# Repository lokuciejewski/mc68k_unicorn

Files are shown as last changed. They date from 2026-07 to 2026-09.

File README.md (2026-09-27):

# Unicorn - a mc68k-based SBC

This SBC was created with one goal in mind - to run UNIX or UNIX-like OS on it. In order to achieve this, the Motorola 68010 had to be chosen since it's the first mc68k family member to support virtual memory (at least in the basic form) and is able to cooperate with a MMU natively.

## Hardware V1

### V1 description

The board is designed in KiCad. The main specs are:

- Motorola 68010 CPU @ 8.192Mhz
- 1MB of SRAM in the form of 2x AS6C4008 (512k x 8) modules
- 64kB of ROM in the form of 2x AT28C256 (32k x 8) modules
- Xilinx xc9572xl CPLD used as glue logic and simple PMMU
- Motorola MC68681 DUART chip for IO
- PCF8584P I2C controller

The board uses two voltage rails, 5V and 3V3, with the latter being used to power the CPLD only and the rest of the system being powered from the 5V. The 3V3 regulator derives its voltage from the 5V rail which is supplied via the USB-C plug which also doubles as the UART1 (`Serial A`) input/output. The board has a DB9 socket which is connected via MAX232 to the 68681 DUART on UART2 (`Serial B`). Additionally, there is a JTAG header for programming the CPLD and two headers for I2C and SPI. 3 programmable LEDs and 3 inputs are available to the user.

#### Memory map

The memory map is defined by the CPLD and is kept as simple as possible:

|Address range|Size [bytes]|Contents|
|---|---|---|
|0x000000 - 0x00FFFF|64k|ROM|
|0x010000 - 0x1FFFFF|1M|SRAM|
|0x110000 - 0x1100FF|256|68681 DUART|
|0x110100 - 0x1101FF|256|8584P I2C|

### V1 conclusions

The board needed a few small adjustments but otherwise functions correctly. Its main problems are very slow SPI bus (bit-banged) and not enough pins on the CPLD to connect all necessary signals for it to function as the PMMU.

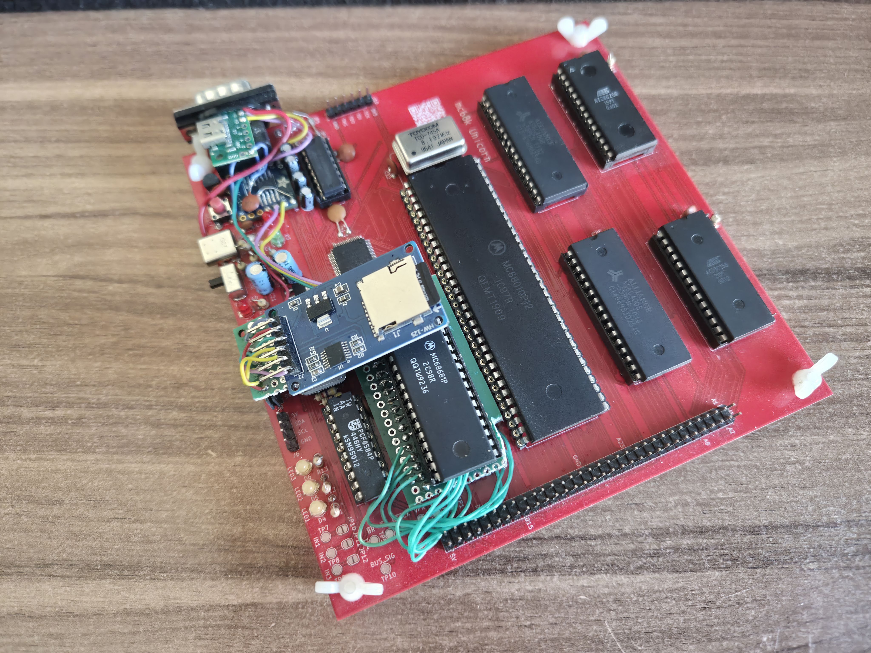
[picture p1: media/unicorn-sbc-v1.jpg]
Unicorn SBC V1 with all its bodge wires :)


## Hardware V2

Changes scheduled for the hardware revision 2:

- Add clock divider circuit to allow for different clocks to be derived and used throughout the system
- Add hardware solution to the SPI - either inside the CPLD or as a separate circuit
- [Optional] Remove the I2C circuit since bit-banged I2C should be sufficient
- Add an RTC on the I2C bus
- Add the SD card slot directly to the board
- Move to the 100 pin version of the CPLD to accomodate all signals
- General layout fixes - USB, DUART data lines etc.

### Further changes

A DRAM controller and a SIMM socket(s) would allow this SBC to address even more memory, up to 68010's 16MB natively and even more through paging. This would require adding a second CPLD or even swapping the current CPLD with a FPGA. While this is not required to reach the goal of running UNIX, it would significantly expand the SBC's capabilities.

## Software

### Firmware description

The board can run any software compiled with the `m68k-elf-gcc` or equivalent m68k compiler. It can utilize its own fork of [`picolibc`](https://github.com/lokuciejewski/picolibc-unicorn) which implements some of the stdlib's functions. The supplied [bootloader](./software/firmware/) allows loading any `.elf` file from the SD card and running it. The bootloader comes with a small monitor - a customized [`tinylisp`](https://github.com/Robert-van-Engelen/tinylisp) implementation.

The bootloader mounts the SD card (FAT16-formatted) and searches for the file named `bootord`. It then tries to load a file that's in the `bootord` into the memory at address `0x10000`. After that, it tries to execute the executable.

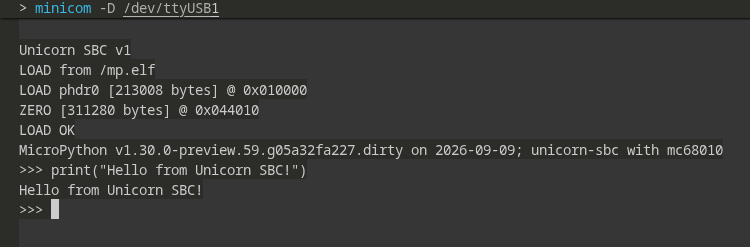
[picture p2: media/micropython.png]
Booting the micropython elf


### Architecture-specific design decisions

Motorola 68010, unlike the 68000 allows for relocating the interrupt vector table into an arbitrary address in its memory space. The Unicorn SBC's bootloader allocates the interrupt vector table at the top of its base 1M of SRAM, at address `0x10FC00`. This 1KB is reserved by the system and must never be accessed by the application directly.

### Compiling the software

#### Requirements

- [`m68k-elf-gcc`](https://github.com/kentosama/m68k-elf-gcc) compiler or any other C compiler that supports the m68k architecture. With a bit of fiddling, the newer GCC can be built, I used `gcc-16.2.0` with the following configuration options: `--prefix=/tmp/m68k-elf-gcc/m68k-toolchain --build=x86_64-pc-linux-gnu --host=x86_64-pc-linux-gnu --target=m68k-elf --program-prefix=m68k-elf- --enable-languages=c --enable-obsolete --enable-lto --disable-threads --disable-libmudflap --disable-libgomp --disable-nls --disable-werror --disable-libssp --disable-shared --disable-multilib --disable-libgcj --disable-libstdcxx --disable-gcov --without-headers --without-included-gettext --with-cpu=m68010 --with-newlib`
- [A fork of `picolibc`](https://github.com/lokuciejewski/picolibc-unicorn) which needs to be installed into the above toolchain
- An SD card formatted in FAT16

The [`example-app`](./software/apps/example_app/) can be used as a base for any software that is to be compiled and ran on the Unicorn SBC. The most important are the [`linker script`](./software/apps/example_app/unicorn_app_v1.ld), the [`crt0.c`](./software/apps/example_app/crt0.c) and the [`CMakeLists.txt`](./software/apps/example_app/CMakeLists.txt).

#### Caveats

The `picolibc` automatically allocates all unused memory reserved for the application in the linker script as a heap space, so during the compilation it will always show 100% memory is consumed. As far as I know, there is no way of limiting the size except for setting the minimum heap size.

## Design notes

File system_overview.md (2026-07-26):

# mc68k SBC - Unicorn v1

## System Overview

- CPU: mc68c010 @ 4Mhz
- RAM: 2x 512k AS6C4008-55PCN SRAM
- ROM: 2x AT28c256 EEPROM
- MMU & glue logic: xc9572xl CPLD
- Peripherals:
  - 68681 DPUART chip - one UART connected via FT231 to USB-C and another connected via MAX232 to DB-9
  - SPI-capable (software) bus from 68681
  - I2C bus using PCF8584
- Power: 5V rail from the USB-C and 3v3 rail derived using ams1117-3.3

## Memory map

A first simple memory map to test the board and get the system running.

0x000000 - 0x00ffff: ROM
0x010000 - 0x03ffff: SRAM (user space)
0x040000 - 0x10ffff: SRAM (kernel space)
0x110000 - 0x110fff: 68681 DPUART (UART1, UART2 and SPI)
0x111000 - 0x111fff: PCF8584 (I2C)

## Glue logic

xc9572xl is connected to all necessary lines to perform the role of a glue logic:

- Address lines:
  - A1 --> PIN1
  - A2 --> PIN2
  - A3 --> PIN4
  - A4 --> PIN5
  - A5 --> PIN6
  - A6 --> PIN7
  - A7 --> PIN8
  - A8 --> PIN9
  - A9 --> PIN10
  - A10 --> PIN11
  - A11 --> PIN12
  - A12 --> PIN13
  - A13 --> PIN15
  - A14 --> PIN16
  - A15 --> PIN17
  - A16 --> PIN18
  - A17 --> PIN19
  - A18 --> PIN20
  - A19 --> PIN22
  - A20 --> PIN23
  - A21 --> PIN24
  - A22 --> PIN25
  - A23 --> PIN27
- CPU signals:
  - /AS --> PIN31
  - /UDS --> PIN32
  - /LDS --> PIN33
  - /DTACK --> PIN34
  - /RW --> PIN35
  - CLK --> PIN36
  - /IPL0 --> PIN38
  - /IPL1 --> PIN39
  - /IPL2 --> PIN40
  - /RES --> PIN42
  - /HALT --> PIN43
  - FC2 --> PIN44
  - FC1 --> PIN45
  - FC0 --> PIN46
- Glue logic signals:
  - /ROM_CS --> PIN47
  - /ROM_LB_OE --> PIN48 (ROM Lower Byte OE)
  - /ROM_UB_OE --> PIN49 (ROM Upper Byte OE)
  - /RAM_CS --> PIN50
  - /RAM_LB_OE --> PIN51 (RAM Lower Byte OE)
  - /RAM_UB_OE --> PIN52 (RAM Upper Byte OE)
  - /RAM_LB_WE --> PIN56
  - /RAM_UB_WE --> PIN57
  - /I2C_CS --> PIN58
  - /I2C_IACK --> PIN59
  - /I2C_IRQ --> PIN60
  - /68681_CS --> PIN61
  - /68681_IACK --> PIN62
  - /68681_IRQ --> PIN63
  - PLD_SIG --> PIN64 (signal to/from the expander)

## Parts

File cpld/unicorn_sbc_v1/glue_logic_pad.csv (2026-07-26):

Release 8.1i - Fit P.20131013
Copyright(c) 1995-2003 Xilinx Inc. All rights reserved
7-26-2026 7:06PM
NOTE: This file is designed to be imported into a spreadsheet program
such as Microsoft Excel for viewing | printing and sorting. The comma ' | '
character is used as the data field separator.
This file is also designed to support parsing.
Input file: glue_logic.ngd
output file: glue_logic_pad.csv
Part type: xc9572xl
Speed grade: -10
Package: vq64
Pinout by Pin Number:
----- | ----- | ----- | ----- | ----- | ----- | ----- | ----- | ----- | -----
Pin Number | Signal Name | Pin Usage | Pin Name | Direction | IO Standard | IO Bank Number | {blank} | Slew Rate | Termination | {blank} | Voltage | Constraint
P1 | I2C_IRQ_n | I | I/O | INPUT
P2 | RES_n | GTS | I/O/GTS2
P3 | VCC |  | VCCINT
P4 | ROM_LB_OE_n | O | I/O | OUTPUT
P5 | A15 | I | I/O/GTS1 | INPUT
P6 | ROM_UB_OE_n | O | I/O | OUTPUT
P7 | TIE |  | I/O
P8 | UDS_n | I | I/O | INPUT
P9 | IPL0_n | O | I/O | OUTPUT
P10 | A16 | I | I/O | INPUT
P11 | TIE |  | I/O
P12 | A19 | I | I/O | INPUT
P13 | A21 | I | I/O | INPUT
P14 | GND |  | GND
P15 | AS_n | GCK/I | I/O/GCK1
P16 | CLK | GCK | I/O/GCK2
P17 | TIE |  | I/O/GCK3
P18 | ROM_CS_n | O | I/O | OUTPUT
P19 | RAM_CS_n | O | I/O | OUTPUT
P20 | TIE |  | I/O
P21 | GND |  | GND
P22 | IPL2_n | O | I/O | OUTPUT
P23 | TIE |  | I/O
P24 | I2C_IACK_n | O | I/O | OUTPUT
P25 | TIE |  | I/O
P26 | VCC |  | VCCIO
P27 | BERR_n | O | I/O | OUTPUT
P28 | TDI |  | TDI
P29 | TMS |  | TMS
P30 | TCK |  | TCK
P31 | TIE |  | I/O
P32 | TIE |  | I/O
P33 | TIE |  | I/O
P34 | DPUART_IACK_n | O | I/O | OUTPUT
P35 | HALT_n | O | I/O | OUTPUT
P36 | A9 | I | I/O | INPUT
P37 | VCC |  | VCCINT
P38 | A22 | I | I/O | INPUT
P39 | A20 | I | I/O | INPUT
P40 | IPL1_n | O | I/O | OUTPUT
P41 | GND |  | GND
P42 | A17 | I | I/O | INPUT
P43 | DTACK_n | O | I/O | OUTPUT
P44 | DPUART_CS_n | O | I/O | OUTPUT
P45 | A12 | I | I/O | INPUT
P46 | A11 | I | I/O | INPUT
P47 | A23 | I | I/O | INPUT
P48 | RW_n | I | I/O | INPUT
P49 | A18 | I | I/O | INPUT
P50 | RAM_LB_OE_n | O | I/O | OUTPUT
P51 | I2C_CS_n | O | I/O | OUTPUT
P52 | A14 | I | I/O | INPUT
P53 | TDO |  | TDO
P54 | GND |  | GND
P55 | VCC |  | VCCIO
P56 | A13 | I | I/O | INPUT
P57 | A10 | I | I/O | INPUT
P58 | DPUART_IRQ_n | I | I/O | INPUT
P59 | LDS_n | I | I/O | INPUT
P60 | RAM_LB_WE_n | O | I/O | OUTPUT
P61 | RAM_UB_OE_n | O | I/O | OUTPUT
P62 | A8 | I | I/O | INPUT
P63 | RAM_UB_WE_n | O | I/O | OUTPUT
P64 | TIE |  | I/O/GSR
To preserve the pinout above for future design iterations in
Project Navigator simply execute the (Lock Pins) process
located under the (Implement Design) process in a toolbox named
(Optional Implementation Tools) or invoke PIN2UCF from the
command line. The location constraints will be written into your
specified UCF file

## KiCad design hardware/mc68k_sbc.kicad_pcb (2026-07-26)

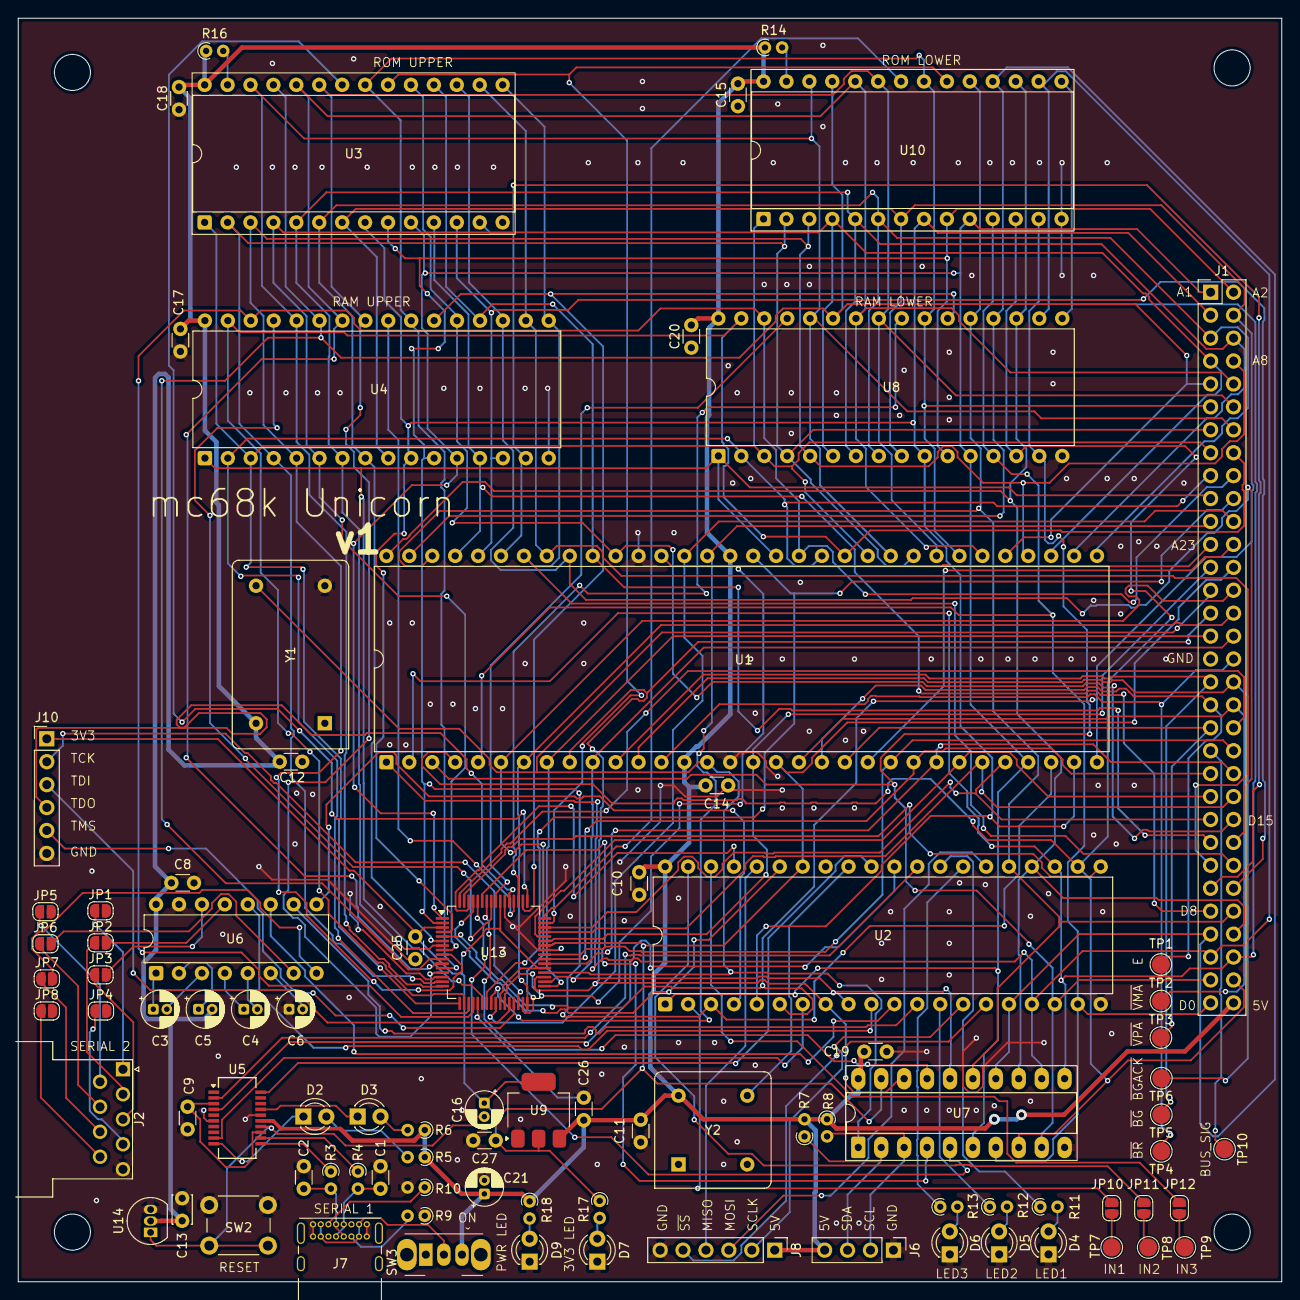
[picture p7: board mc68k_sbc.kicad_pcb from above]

Board: 2 copper layers, 140.0 x 140.0 mm, 88 parts (0 on the bottom side), 144 nets.

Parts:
C1, C2: 47pF; C_Disc_D3.0mm_W1.6mm_P2.50mm
C3, C4, C5, C6: 1uF; CP_Radial_D4.0mm_P1.50mm
C8, C9, C10, C11, C12, C14, C15, C17, C18, C19, C20, C25, C26, C27: 0.1uF; C_Disc_D3.0mm_W1.6mm_P2.50mm
C13: 1uF; C_Disc_D3.0mm_W2.0mm_P2.50mm
C16, C21: 10uF; CP_Radial_D4.0mm_P1.50mm
D2, D3, D4, D5, D6, D7, D9: LED; LED_D3.0mm
J1: EXP; PinHeader_2x32_P2.54mm_Vertical
J2: DE9_Pins; DSUB-9_Pins_Horizontal_P2.77x2.54mm_EdgePinOffset9.40mm
J6: I2C_Conn; PinHeader_1x04_P2.54mm_Vertical
J7: USB_C_Receptacle_USB2.0_14P; USB_C_Receptacle_GCT_USB4085
J8: SPI_Conn; PinHeader_1x06_P2.54mm_Vertical
J10: JTAG_Conn; PinHeader_1x06_P2.54mm_Vertical
JP1: DCD; SolderJumper-2_P1.3mm_Open_RoundedPad1.0x1.5mm
JP2: RXD; SolderJumper-2_P1.3mm_Open_RoundedPad1.0x1.5mm
JP3: TXD; SolderJumper-2_P1.3mm_Open_RoundedPad1.0x1.5mm
JP4: DTR; SolderJumper-2_P1.3mm_Open_RoundedPad1.0x1.5mm
JP5: DSR; SolderJumper-2_P1.3mm_Open_RoundedPad1.0x1.5mm
JP6: RTS; SolderJumper-2_P1.3mm_Open_RoundedPad1.0x1.5mm
JP7: CTS; SolderJumper-2_P1.3mm_Open_RoundedPad1.0x1.5mm
JP8: RI; SolderJumper-2_P1.3mm_Open_RoundedPad1.0x1.5mm
JP10: USER_INPUT_1; SolderJumper-2_P1.3mm_Open_RoundedPad1.0x1.5mm
JP11: USER_INPUT_2; SolderJumper-2_P1.3mm_Open_RoundedPad1.0x1.5mm
JP12: USER_INPUT_3; SolderJumper-2_P1.3mm_Open_RoundedPad1.0x1.5mm
R3, R4: 27R; R_Axial_DIN0204_L3.6mm_D1.6mm_P1.90mm_Vertical
R5, R6, R11, R12, R13, R18: 220R; R_Axial_DIN0204_L3.6mm_D1.6mm_P1.90mm_Vertical
R7, R8: 4k7; R_Axial_DIN0204_L3.6mm_D1.6mm_P1.90mm_Vertical
R9, R10: 5k1; R_Axial_DIN0204_L3.6mm_D1.6mm_P1.90mm_Vertical
R14, R16, R17: 1K; R_Axial_DIN0204_L3.6mm_D1.6mm_P1.90mm_Vertical
SW2: Reset; SW_PUSH_6mm
SW3: Power Switch; SW_Slide_SPDT_Angled_CK_OS102011MA1Q
TP1: E; TestPoint_Pad_D2.0mm
TP2: ~{VMA}; TestPoint_Pad_D2.0mm
TP3: ~{VPA}; TestPoint_Pad_D2.0mm
TP4: ~{BR}; TestPoint_Pad_D2.0mm
TP5: ~{BG}; TestPoint_Pad_D2.0mm
TP6: ~{BGACK}; TestPoint_Pad_D2.0mm
TP7: USER_INPUT_1; TestPoint_Pad_D2.0mm
TP8: USER_INPUT_2; TestPoint_Pad_D2.0mm
TP9: USER_INPUT_3; TestPoint_Pad_D2.0mm
TP10: BUS_SIG; TestPoint_Pad_D2.0mm
U1: MC68000P/MC68010P; DIP-64_W22.86mm
U2: 68681; DIP-40_W15.24mm
U3, U10: 28C256; DIP-28_W15.24mm_Socket
U4, U8: AS6C4008-55PCN; DIP-32_W15.24mm
U5: FT231XS; SSOP-20_3.9x8.7mm_P0.635mm
U6: MAX232; DIP-16_W7.62mm
U7: PCF8584; DIP-20_W7.62mm_Socket_LongPads
U9: AMS1117-3.3; SOT-223-3_TabPin2
U13: XC9572XL-xxVQx64; TQFP-64_10x10mm_P0.5mm
U14: MCP100-450D; TO-92_Inline
Y1: CXO_DIP14; Oscillator_DIP-14
Y2: CXO_DIP8; Oscillator_DIP-8

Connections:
+3.3V: C16.1, C25.1, C27.2, J10.1, R17.1, U9.2 (VO), U13.3 (VCCINT), U13.26 (VCCIO), U13.37 (VCCINT), U13.55 (VCCIO)
/A1: J1.1, U1.29 (A1), U2.1 (RS1), U3.10 (A0), U4.12 (A0), U7.6 (A0), U8.12 (A0), U10.10 (A0), U13.1 (I/O)
/A2: J1.2, U1.30 (A2), U2.3 (RS2), U3.9 (A1), U4.11 (A1), U8.11 (A1), U10.9 (A1), U13.2 (I/O/GTS2)
/A3: J1.3, U1.31 (A3), U2.5 (RS3), U3.8 (A2), U4.10 (A2), U8.10 (A2), U10.8 (A2), U13.4 (I/O)
/A4: J1.4, U1.32 (A4), U2.6 (RS4), U3.7 (A3), U4.9 (A3), U8.9 (A3), U10.7 (A3), U13.5 (I/O/GTS1)
/A5: J1.5, U1.33 (A5), U3.6 (A4), U4.8 (A4), U8.8 (A4), U10.6 (A4), U13.6 (I/O)
/A6: J1.6, U1.34 (A6), U3.5 (A5), U4.7 (A5), U8.7 (A5), U10.5 (A5), U13.7 (I/O)
/A7: J1.7, U1.35 (A7), U3.4 (A6), U4.6 (A6), U8.6 (A6), U10.4 (A6), U13.8 (I/O)
/A8: J1.8, U1.36 (A8), U3.3 (A7), U4.5 (A7), U8.5 (A7), U10.3 (A7), U13.9 (I/O)
/A9: J1.9, U1.37 (A9), U3.25 (A8), U4.27 (A8), U8.27 (A8), U10.25 (A8), U13.10 (I/O)
/A10: J1.10, U1.38 (A10), U3.24 (A9), U4.26 (A9), U8.26 (A9), U10.24 (A9), U13.11 (I/O)
/A11: J1.11, U1.39 (A11), U3.21 (A10), U4.23 (A10), U8.23 (A10), U10.21 (A10), U13.12 (I/O)
/A12: J1.12, U1.40 (A12), U3.23 (A11), U4.25 (A11), U8.25 (A11), U10.23 (A11), U13.13 (I/O)
/A13: J1.13, U1.41 (A13), U3.2 (A12), U4.4 (A12), U8.4 (A12), U10.2 (A12), U13.15 (I/O/GCK1)
/A14: J1.14, U1.42 (A14), U3.26 (A13), U4.28 (A13), U8.28 (A13), U10.26 (A13), U13.16 (I/O/GCK2)
/A15: J1.15, U1.43 (A15), U3.1 (A14), U4.3 (A14), U8.3 (A14), U10.1 (A14), U13.17 (I/O/GCK3)
/A16: J1.16, U1.44 (A16), U4.31 (A15), U8.31 (A15), U13.18 (I/O)
/A17: J1.17, U1.45 (A17), U4.2 (A16), U8.2 (A16), U13.19 (I/O)
/A18: J1.18, U1.46 (A18), U4.30 (A17), U8.30 (A17), U13.20 (I/O)
/A19: J1.19, U1.47 (A19), U4.1 (A18), U8.1 (A18), U13.22 (I/O)
/A20: J1.20, U1.48 (A20), U13.23 (I/O)
/A21: J1.21, U1.50 (A21), U13.24 (I/O)
/A22: J1.22, U1.51 (A22), U13.25 (I/O)
/A23: J1.23, U1.52 (A23), U13.27 (I/O)
/CLK: J1.27, U1.15 (CLK), U7.1 (CLK), U13.36 (I/O), Y1.8 (OUT)
/CTS_DB9: U2.4 (IP1), U6.9 (R2OUT)
/D0: J1.63, U1.5 (D0), U2.19 (D7), U7.7 (D0), U8.13 (DQ0), U10.11 (D0)
/D1: J1.62, U1.4 (D1), U2.22 (D6), U7.8 (D1), U8.14 (DQ1), U10.12 (D1)
/D2: J1.61, U1.3 (D2), U2.18 (D5), U7.9 (D2), U8.15 (DQ2), U10.13 (D2)
/D3: J1.60, U1.2 (D3), U2.23 (D4), U7.11 (D3), U8.17 (DQ3), U10.15 (D3)
/D4: J1.59, U1.1 (D4), U2.17 (D3), U7.12 (D4), U8.18 (DQ4), U10.16 (D4)
/D5: J1.58, U1.64 (D5), U2.24 (D2), U7.13 (D5), U8.19 (DQ5), U10.17 (D5)
/D6: J1.57, U1.63 (D6), U2.16 (D1), U7.14 (D6), U8.20 (DQ6), U10.18 (D6)
/D7: J1.56, U1.62 (D7), U2.25 (D0), U7.15 (D7), U8.21 (DQ7), U10.19 (D7)
/D8: J1.55, U1.61 (D8), U3.11 (D0), U4.13 (DQ0)
/D9: J1.54, U1.60 (D9), U3.12 (D1), U4.14 (DQ1)
/D10: J1.53, U1.59 (D10), U3.13 (D2), U4.15 (DQ2)
/D11: J1.52, U1.58 (D11), U3.15 (D3), U4.17 (DQ3)
/D12: J1.51, U1.57 (D12), U3.16 (D4), U4.18 (DQ4)
/D13: J1.50, U1.56 (D13), U3.17 (D5), U4.19 (DQ5)
/D14: J1.49, U1.55 (D14), U3.18 (D6), U4.20 (DQ6)
/D15: J1.48, U1.54 (D15), U3.19 (D7), U4.21 (DQ7)
/D+: C2.1, J7.A6 (D+), J7.B6 (D+), R3.2
/D-: C1.2, J7.A7 (D-), J7.B7 (D-), R4.2
/DB1: J2.1, JP1.1 (A)
/DB2: J2.2, JP2.1 (A)
/DB3: J2.3, JP3.1 (A)
/DB4: J2.4, JP4.1 (A)
/DB6: J2.6, JP5.1 (A)
/DB7: J2.7, JP6.1 (A)
/DB8: J2.8, JP7.1 (A)
/DB9: J2.9, JP8.1 (A)
/E: J1.37, TP1.1 (1_1), U1.20 (E)
/FC0: J1.47, U1.28 (FC0), U13.46 (I/O)
/FC1: J1.46, U1.27 (FC1), U13.45 (I/O)
/FC2: J1.45, U1.26 (FC2), U13.44 (I/O)
/PLD_SIG: J1.40, U13.64 (I/O/GSR)
/R1IN: JP2.2 (B), U6.13 (R1IN)
/R2IN: JP7.2 (B), U6.8 (R2IN)
/RTS_DB9: U2.12 (OP1), U6.10 (T2IN)
/RX_DB9: U2.10 (RXDB), U6.12 (R1OUT)
/RX_USB: U2.30 (TXDA), U5.4 (RXD)
/R/~W: J1.29, U1.9 (R/~W), U2.8 (R/W), U7.18 (~WR), U13.35 (I/O)
/SPI_MISO: J8.4, U2.36 (IP2)
/SPI_MOSI: J8.3, U2.26 (OP6)
/SPI_SCLK: J8.2, U2.14 (OP5)
/T1OUT: JP3.2 (B), U6.14 (T1OUT)
/T2OUT: JP6.2 (B), U6.7 (T2OUT)
/TX_DB9: U2.11 (TXDB), U6.11 (T1IN)
/TX_USB: U2.31 (RXDA), U5.20 (TXD)
/USER_LED_1: R11.1, U2.28 (OP2)
/USER_LED_2: R12.1, U2.13 (OP3)
/USER_LED_3: R13.1, U2.27 (OP4)
/VBUS: J7.A4 (VBUS), J7.A9 (VBUS), J7.B4 (VBUS), J7.B9 (VBUS), SW3.2 (B)
/~68681_CS: U2.35 (CS), U13.61 (I/O)
/~68681_IACK: U2.37 (IACK), U13.62 (I/O)
/~68681_IRQ: U2.21 (IRQ), U13.63 (I/O)
/~AS: J1.28, U1.6 (~AS), U13.31 (I/O)
/~BERR: J1.24, U1.22 (~BERR)
/~BGACK: J1.36, TP6.1 (1_1), U1.12 (~BGACK)
/~BG: J1.35, TP5.1 (1_1), U1.11 (~BG)
/~BR: J1.34, TP4.1 (1_1), U1.13 (~BR)
/~CTS_USB: U2.7 (IP0), U5.9 (~CTS)
/~DTACK: J1.32, U1.10 (~DTACK), U2.9 (DTACK), U7.16 (~RD), U13.34 (I/O)
/~HALT: J1.25, U1.17 (~HALT), U13.43 (I/O)
/~I2C_CS: U7.17 (~CS), U13.58 (I/O)
/~I2C_IACK: U7.4 (~IACK), U13.59 (I/O)
/~I2C_IRQ: U7.5 (~INT), U13.60 (I/O)
/~IPL0: J1.44, U1.25 (~IPL0), U13.38 (I/O)
/~IPL1: J1.43, U1.24 (~IPL1), U13.39 (I/O)
/~IPL2: J1.42, U1.23 (~IPL2), U13.40 (I/O)
/~LDS: J1.31, U1.8 (~LDS), U13.33 (I/O)
/~RAM_CS: U4.22 (CE#), U8.22 (CE#), U13.50 (I/O)
/~RAM_LB_OE: U8.24 (OE#), U13.51 (I/O)
/~RAM_LB_WE: U8.29 (WE#), U13.56 (I/O)
/~RAM_UB_OE: U4.24 (OE#), U13.52 (I/O)
/~RAM_UB_WE: U4.29 (WE#), U13.57 (I/O)
/~RES: J1.26, SW2.1, U1.18 (~RESET), U2.34 (RESET), U5.14 (~RESET), U7.19 (~RST), U13.42 (I/O), U14.1 (~RST)
/~ROM_CS: U3.20 (~CS), U10.20 (~CS), U13.47 (I/O)
/~ROM_LB_OE: U10.22 (~OE), U13.48 (I/O)
/~ROM_UB_OE: U3.22 (~OE), U13.49 (I/O)
/~RTS_USB: U2.29 (OP0), U5.2 (~RTS)
/~SPI_SS: J8.5, U2.15 (OP7)
/~UDS: J1.30, U1.7 (~UDS), U13.32 (I/O)
/~VMA: J1.38, TP2.1 (1_1), U1.19 (~VMA)
/~VPA: J1.39, TP3.1 (1_1), U1.21 (~VPA)
GND: C1.1, C2.2, C6.1, C8.2, C9.2, C10.2, C11.2, C12.2, C13.1, C14.2, C15.2, C16.2, C17.2, C18.2, C19.2, C20.2, C21.2, C25.2, C26.1, C27.1, D4.1 (K), D5.1 (K), D6.1 (K), D7.1 (K), D9.1 (K), J1.33, J2.5, J6.1, J7.A1 (GND), J7.A12 (GND), J7.B1 (GND), J7.B12 (GND), J8.6, J10.6, R9.1, R10.2, SW2.2, U1.16 (GND), U1.53 (GND), U2.20 (GND), U3.14 (GND), U4.16 (VSS), U5.6 (GND), U5.16 (GND), U6.15 (GND), U7.10 (VSS), U8.16 (VSS), U9.1 (GND), U10.14 (GND), U13.14 (GND), U13.21 (GND), U13.41 (GND), U13.54 (GND), U14.3 (VSS), Y1.7 (GND), Y2.4 (GND)
unnamed: D2.2 (A), R5.2
unnamed: D2.1 (K), U5.10 (CBUS2)
unnamed: D3.2 (A), R6.2
unnamed: D3.1 (K), U5.17 (CBUS1)
unnamed: D4.2 (A), R11.2
unnamed: D5.2 (A), R12.2
unnamed: D6.2 (A), R13.2
unnamed: D7.2 (A), R17.2
unnamed: D9.2 (A), R18.2
unnamed: J1.41, TP10.1 (1_1)
unnamed: J6.2, R8.2, U7.3 (SCL)
unnamed: J6.3, R7.1, U7.2 (SDA)
unnamed: J7.A5 (CC1), R10.1
unnamed: J7.B5 (CC2), R9.2
unnamed: J10.2, U13.30 (TCK)
unnamed: J10.3, U13.28 (TDI)
unnamed: J10.4, U13.53 (TDO)
unnamed: J10.5, U13.29 (TMS)
unnamed: JP10.1 (A), U2.2 (IP3)
unnamed: JP10.2 (B), TP7.1 (1_1)
unnamed: JP11.1 (A), U2.39 (IP4)
unnamed: JP11.2 (B), TP8.1 (1_1)
unnamed: JP12.1 (A), U2.38 (IP5)
unnamed: JP12.2 (B), TP9.1 (1_1)
unnamed: U2.32 (X1/CLK), Y2.5 (OUT)
unnamed: R16.2, U3.27 (~WE)
unnamed: C9.1, U5.3 (VCCIO), U5.13 (3V3OUT)
unnamed: R4.1, U5.12 (USBDM)
unnamed: R3.1, U5.11 (USBDP)
unnamed: C3.1, U6.1 (C1+)
unnamed: C3.2, U6.3 (C1-)
unnamed: C4.1, U6.4 (C2+)
unnamed: C4.2, U6.5 (C2-)
unnamed: C5.1, U6.2 (VS+)
unnamed: C6.2, U6.6 (VS-)
unnamed: R14.2, U10.27 (~WE)
VCC: C5.2, C8.1, C10.1, C11.1, C12.1, C13.2, C14.1, C15.1, C17.1, C18.1, C19.1, C20.1, C21.1, C26.2, J1.64, J6.4, J8.1, R5.1, R6.1, R7.2, R8.1, R14.1, R16.1, R18.1, SW3.3 (C), U1.14 (V_{CC}), U1.49 (V_{CC}), U2.40 (VCC), U3.28 (VCC), U4.32 (VCC), U5.15 (VCC), U6.16 (VCC), U7.20 (VDD), U8.32 (VCC), U9.3 (VI), U10.28 (VCC), U14.2 (VDD), Y1.14 (Vcc), Y2.8 (Vcc)

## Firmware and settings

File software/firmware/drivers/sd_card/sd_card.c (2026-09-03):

#include "api/sd_card.h"
#include "../../hal/inc/gpio.h"
#include "../../hal/inc/spi.h"
#include "../../hal/inc/time.h"
#include "system/result_codes.h"
#include <stdbool.h>
#include <string.h>

#define SD_ReadByte()                                                          \
  SPI_WriteByteNoSel(0xff) // SD card expects MOSI to be default high

#define SD_WriteByte(byte) SPI_WriteByteNoSel(byte)

// CMD0 - GO_IDLE_STATE
#define CMD0 0
#define CMD0_ARG 0
#define CMD0_CRC 0x94

// CMD8 - SEND_IF_COND (Send Interface Condition)
#define CMD8 8
#define CMD8_ARG 0x0000001AA // 3.3V
#define CMD8_CRC 0x86

// CMD58 - READ_OCR (Read Operation Condition Register)
#define CMD58 58
#define CMD58_ARG 0
#define CMD58_CRC 0 // not needed unless enabled explicitly

// CMD55 - APP_CMD (Informs the SD card that the next command is an
// application-specific command)
#define CMD55 55
#define CMD55_ARG 0
#define CMD55_CRC 0

// ACMD41 - SD_SEND_OP_COND (Send Operating Condition)
#define ACMD41 41
#define ACMD41_ARG 0x40000000
#define ACMD41_CRC 0

// CMD17 - READ_SINGLE_BLOCK
#define CMD17 17
#define CMD17_CRC 0

// CMD18 - READ_MULTIPLE_BLOCK
#define CMD18 18
#define CMD18_CRC 0

// CMD12 - STOP_ALL_TRANSMISSIONS
#define CMD12 12
#define CMD12_CRC 0

// CMD24 - WRITE_SINGLE_BLOCK
#define CMD24 24
#define CMD24_CRC 0

// 100ms timeout while clocking is needed. It takes around 320us for a single
// byte to be sent/read. 100ms is 312.5*320us so to make it safer:
#define SD_MAX_READ_ATTEMPTS 320U
// 250ms timeout while clocking is needed. Using same math as for read, it
// needs 2.5 * 320 attempts, so:
#define SD_MAX_WRITE_ATTEMPTS 800U

#define SD_START_BLOCK 0xfe
#define SD_BLOCK_SIZE 512U

typedef enum {
  SD_Response1,
  SD_Response3,
  SD_Response7,
} SD_Response_e;

static void SD_Select(void) {
  GPIO_Led_Set(Led_3, true);
  SD_ReadByte(); // Send 8 clocks before and after CS to ensure the
                 // SD card is selected
  SPI_Select(true);
  SD_ReadByte();
}

static void SD_Deselect(void) {
  SD_ReadByte(); // Send 8 clocks before and after CS to ensure the
                 // SD card is deselected
  SPI_Select(false);
  SD_ReadByte();
  GPIO_Led_Set(Led_3, false);
}

static void SD_SendCommand(uint8_t command, uint32_t arg, uint8_t crc) {
  SD_WriteByte(command |
               0x40); // SD commands are "prefixed" on the 2 MS bits with 0b01

  SD_WriteByte((uint8_t)(arg >> 24));
  SD_WriteByte((uint8_t)(arg >> 16));
  SD_WriteByte((uint8_t)(arg >> 8));
  SD_WriteByte((uint8_t)(arg));

  SD_WriteByte(crc | 0b1); // SD command must end with 1
}

static void SD_ReadResponse1(uint8_t *response) {
  for (uint8_t i = 0; i < 16; i++) {
    response[0] = SD_ReadByte();
    if (response[0] != 0xff) {
      return;
    }
  }
  response[0] = 0xff;
}

static void SD_ReadResponse(SD_Response_e resp, uint8_t *response) {
  switch (resp) {
  case SD_Response1:
    SD_ReadResponse1(response);
    break;
  case SD_Response3:
  case SD_Response7:
    SD_ReadResponse1(response);
    if (response[0] > 0x1) {
      memset(&response[1], 0, 4);
      return;
    }
    for (uint8_t i = 1; i <= 4; i++) {
      response[i] = SD_ReadByte();
    }
    break;
  default:
    break;
  }
}

static UnicornResult_e SD_SendCommand_ACMD41(uint8_t *response,
                                             SD_CardType_e *card_type) {
  for (uint8_t i = 0; i < 100; i++) {
    SD_Select();
    SD_SendCommand(CMD55, CMD55_ARG, CMD55_CRC);
    SD_ReadResponse(SD_Response1, response);
    SD_Deselect();

    SD_Select();
    if (*card_type == SD_V1_SDSC) {
      SD_SendCommand(ACMD41, 0, ACMD41_CRC);
    } else {
      SD_SendCommand(ACMD41, ACMD41_ARG, ACMD41_CRC);
    }
    SD_ReadResponse(SD_Response1, response);
    SD_Deselect();
    if (response[0] == 0x00) {
      return UniRes_Ok;
    }
    delay_ms(10);
  }

  return UniRes_Timeout;
}

static SD_CardType_e card_type = 0;

UnicornResult_e SD_Init(void) {
  SD_Deselect();

  for (uint8_t i = 0; i < 10; i++) {
    SD_ReadByte(); // Send 80 clock cycles to synchronise, card must
                   // be deselected
  }

  uint8_t sd_response[5] = {0};
  uint8_t attempts = 0;
  while (sd_response[0] != 0x01) {
    SD_Select();
    SD_SendCommand(CMD0, CMD0_ARG, CMD0_CRC);
    SD_ReadResponse(SD_Response1, sd_response);
    SD_Deselect();
    attempts++;
    if (attempts > 10) {
      return UniRes_Timeout;
    }
  }

  SD_Select();
  SD_SendCommand(CMD8, CMD8_ARG, CMD8_CRC);
  SD_ReadResponse(SD_Response7, sd_response);
  SD_Deselect();
  if (sd_response[0] == 0x01) {
    // The SD card is version >=2.00
    // Check voltage response
    if (sd_response[3] != 0x01) {
      return UniRes_SD_IncompatibleVoltageRange;
    }

    // Check echoed pattern
    if (sd_response[4] != 0xaa) {
      return UniRes_SD_CheckPatternMismatch;
    }

    SD_Select();
    SD_SendCommand(CMD58, CMD58_ARG, CMD58_CRC);
    SD_ReadResponse(SD_Response3,
                    sd_response); // Response ignored but must be read
    SD_Deselect();

    UnicornResult_e result = SD_SendCommand_ACMD41(sd_response, &card_type);
    if (result != UniRes_Ok) {
      return result;
    }

    SD_Select();
    SD_SendCommand(CMD58, CMD58_ARG, CMD58_CRC);
    SD_ReadResponse(SD_Response3,
                    sd_response); // Now response contains valid data
    SD_Deselect();

    if (!(sd_response[1] & 0x80)) {
      return UniRes_SD_PowerUpBitNotSet;
    }

    if (sd_response[1] & 0x40) {
      card_type = SD_V2_SDHC_SDXC;
    } else {
      card_type = SD_V2_SDSC;
    }

  } else if (sd_response[0] == 0x05) {
    // Illegal command indicates the SD card if first gen or MMC
    card_type = SD_V1_SDSC;
    SD_SendCommand_ACMD41(sd_response, &card_type);
    if (sd_response[0] & 0b100) {
      return UniRes_SD_NotSDCard;
    }
    if (sd_response[0] != UniRes_Ok) {
      return UniRes_Timeout;
    }
  } else {
    return UniRes_GeneralError;
  }

  return UniRes_Ok;
}

SD_CardType_e SD_Type(void) { return card_type; }

// `ops` should be `SD_MAX_READ_ATTEMPTS` or `SD_MAX_WRITE_ATTEMPTS`
static uint8_t SD_WaitForReady(uint16_t ops) {
  uint8_t read = 0xff;
  for (uint16_t i = 0; i < ops; i++) {
    read = SD_ReadByte();
    if (read != 0xff) {
      return read;
    }
  }
  return 0xff;
}
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

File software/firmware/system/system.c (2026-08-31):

#include "system.h"
#include "../hal/inc/serial.h"
#include "../hal/inc/time.h"
#include "ff.h"
#include "gpio.h"
#include "sd_card.h"
#include "syscalls.h"
#include <fcntl.h>
#include <stddef.h>
#include <stdio.h>
#include <stdlib.h>

extern int tinylisp();

static volatile Serial_Instance_e current_instance = Serial_A;

static void Serial_SetStdio(Serial_Instance_e serial) {
  current_instance = serial;
}

static void t15_exit() {
  tinylisp();
  while (1) {
  }
}

static size_t t15_write(int fd, const uint8_t *buf, size_t count) {
  switch (fd) {
  case 0: // stdout
  case 1: // stdin
  case 2: // stderr
    return Serial_WriteBytes(Serial_A, buf, count);
  default:
    // invalid fd
    break;
  }
  return 0;
}

static size_t t15_read(int fd, uint8_t *buf, size_t count) {
  switch (fd) {
  case 0: // stdout
  case 1: // stdin
  case 2: // stderr
    return Serial_ReadBytes(Serial_A, buf, count);
  default:
    // invalid fd
    break;
  }
  return 0;
}

static int t15_open([[maybe_unused]] const char *path,
                    [[maybe_unused]] int mode) {
  return 0;
}

static int t15_close([[maybe_unused]] int fd) { return 0; }

static off_t t15_lseek([[maybe_unused]] int fd, [[maybe_unused]] off_t offset,
                       [[maybe_unused]] int whence) {
  return 0;
}

uint32_t Trap15_Handler(uint32_t func_id, uint32_t arg1, uint32_t arg2,
                        uint32_t arg3) {
  switch ((SyscallFunc_e)func_id) {
  case Syscall_Version:
    return TRAP_API_VERSION;
  case Syscall_Serial_Init: {
    const Serial_Settings_t *settings = (const Serial_Settings_t *)arg1;
    Serial_Init(settings);
    break;
  }
  case Syscall_Serial_Putc: {
    Serial_Instance_e inst = (Serial_Instance_e)arg1;
    char c = (char)(arg2);
    Serial_Putc((const Serial_Instance_e)inst, c);
    break;
  }
  case Syscall_Serial_Getc: {
    Serial_Instance_e inst = (Serial_Instance_e)arg1;
    return Serial_Getc((const Serial_Instance_e)inst);
  }
  case Syscall_Serial_GetcT: {
    Serial_Instance_e inst = (Serial_Instance_e)arg1;
    uint16_t timeout_ms = (uint16_t)arg2;
    char *c = (char *)arg3;
    return Serial_GetcT((const Serial_Instance_e)inst, timeout_ms, c);
  }
  case Syscall_Serial_PrintStr: {
    Serial_Instance_e inst = (Serial_Instance_e)arg1;
    const char *c = (const char *)(arg2);
    Serial_PrintStr((const Serial_Instance_e)inst, (const char *)c);
    break;
  }
  case Syscall_Serial_SetStdio: {
    Serial_Instance_e inst = (Serial_Instance_e)arg1;
    Serial_SetStdio((const Serial_Instance_e)inst);
    break;
  }
  case Syscall_Time_DelayMs: {
    uint32_t ms = arg1;
    delay_ms(ms);
    break;
  }
  case Syscall_Time_Delay2us: {
    delay_2us();
    break;
  }
  case Syscall_GPIO_Led_Set: {
    GPIO_Led_e led = (GPIO_Led_e)arg1;
    bool state = (bool)arg2;
    GPIO_Led_Set(led, state);
    break;
  }
  case Syscall_SD_Init:
    return SD_Init();
  case Syscall_SD_ReadBlock: {
    uint32_t block_num = arg1;
    uint8_t *buffer = (uint8_t *)arg2;
    return SD_ReadBlock(block_num, buffer);
  }
  case Syscall_SD_WriteBlock: {
    uint32_t block_num = arg1;
    const uint8_t *buffer = (const uint8_t *)arg2;
    return SD_WriteBlock(block_num, buffer);
  }
  case Syscall_SD_Sync:
    return SD_Sync();
  // POSIX syscalls
  case Syscall_Putc:
    char c = (char)arg1;
    Serial_Putc(current_instance, c);
    break;
  case Syscall_Getc:
    return Serial_Getc(current_instance);
  case Syscall_Exit:
    t15_exit();
    break;
  case Syscall_Open:
    return t15_open((const char *)arg1, (int)arg2);
  case Syscall_Close:
    return t15_close((int)arg1);
  case Syscall_Lseek:
    return t15_lseek((int)arg1, (off_t)arg2, (int)arg3);
  case Syscall_Write: {
    int fd = (int)arg1;
    const uint8_t *buf = (const uint8_t *)arg2;
    size_t count = (size_t)arg3;
    return t15_write(fd, buf, count);
  }
  case Syscall_Read: {
    int fd = (int)arg1;
    uint8_t *buf = (uint8_t *)arg2;
    size_t count = (size_t)arg3;
    return t15_read(fd, buf, count);
  }
  }

  return 0;
}

static FIL *files[MAX_CONCURRENTLY_OPEN_FILES] = {nullptr};

static BYTE convert_posix_to_fatfs_flags(int flags) {
  BYTE fatfs_flags = 0;
  switch (flags & O_ACCMODE) {
  case O_RDONLY:
    fatfs_flags |= FA_READ;
    break;
  case O_WRONLY:
    fatfs_flags |= FA_WRITE;
    break;
  case O_RDWR:
    fatfs_flags |= FA_READ | FA_WRITE;
    break;
  default:
    return 0; // Invalid flags
  }

  if (flags & O_CREAT) {
    if (flags & O_EXCL) {
      fatfs_flags |= FA_CREATE_NEW;
    } else if (flags & O_TRUNC) {
      fatfs_flags |= FA_CREATE_ALWAYS;
    } else {
      fatfs_flags |= FA_OPEN_ALWAYS;
    }
  } else {
    if (flags & O_TRUNC) {
      // POSIX allows O_TRUNC without O_CREAT, no equivalent for fatfs, instead
      // open existing and truncate.
      fatfs_flags |= FA_CREATE_ALWAYS;
    } else {
      fatfs_flags |= FA_OPEN_EXISTING;
    }
  }

  if (flags & O_APPEND) {
    fatfs_flags |= FA_OPEN_APPEND;
  }

  return fatfs_flags;
}

static int t14_open(const char *path, uint32_t flags,
                    [[maybe_unused]] int mode) {
  int first_empty = -1;
  for (int i = 0; i < (int)MAX_CONCURRENTLY_OPEN_FILES; i++) {
    if (files[i] == nullptr) {
      first_empty = i;
      break;
    }
  }
  if (first_empty == -1) {
    return first_empty; // Too many open files
  }
  files[first_empty] = malloc(sizeof(FIL));
  FRESULT res =
      f_open(files[first_empty], path, convert_posix_to_fatfs_flags(flags));
  if (res != FR_OK) {
    free(files[first_empty]);
    files[first_empty] = nullptr;
    return -res;
  }
  return first_empty + FD_FIRST_FOR_FS;
}

static int t14_close(int fd) {
  size_t idx = (size_t)fd - FD_FIRST_FOR_FS;
  FRESULT res = f_close(files[idx]); // TODO: convert to UnicornResult??
  if (res == FR_OK) {
    free(files[idx]);
    files[idx] = nullptr;
  }
  return res;
}

static off_t t14_lseek(int fd, off_t offset, int whence) {
  switch (fd) {
  case 0:      // stdout
  case 1:      // stdin
  case 2:      // stderr
    return -1; // invalid fd
  default: {
    off_t new_offset = 0;
    size_t idx = fd - FD_FIRST_FOR_FS;
    switch (whence) {
    case SEEK_SET:
      new_offset = offset;
      break;
    case SEEK_CUR:
      new_offset = (off_t)files[idx]->fptr + offset;
      break;
    case SEEK_END:
      new_offset = (off_t)files[idx]->obj.objsize + offset;
      break;
    }
    if (new_offset < 0) {
      return -1;
    }
    if (f_lseek(files[idx], new_offset) != FR_OK) {
      return -1;
    }
    return new_offset;
  }
  }
}

static size_t t14_write(int fd, const uint8_t *buf, size_t count) {
  switch (fd) {
  case 0:     // stdout
  case 1:     // stdin
  case 2:     // stderr
    return 0; // invalid fd
  default: {
    size_t idx = fd - FD_FIRST_FOR_FS;
    UINT bytes_written = 0;
    (void)f_write(files[idx], buf, count, &bytes_written);
    (void)f_sync(files[idx]); // TODO: is this necessary?
    return bytes_written;
  }
  }
}
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

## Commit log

2026-07-29 fixed supervisor stack overlapping with IRQ_TABLE
    [bootloader.c, serial.c]
2026-08-07 changed to tinylisp, added time and spi hal components
2026-08-15 added I2C hal (WIP), added timeoutable Getc, added result codes
2026-08-31 reworked loading of elfs, load_elf now works, apps can return to bootloader
    [bootloader.c, system.c]
2026-09-03 added sd card command 18 (multiple block reads), added prints to bootloader
2026-09-10 added bootord autoboot for bootloader, updated schematics
    [mc68k_sbc.kicad_sch]
